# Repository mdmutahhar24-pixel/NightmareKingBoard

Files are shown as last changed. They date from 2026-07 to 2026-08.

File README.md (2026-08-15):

# NightmareKingBoard
A TKL Keyboard based of the Hollow Knight boss Nightmare King Grimm. (Very bad representation)





This keyboard features a red and black case, with RGB lighting, and a rotary encoder. This was coded with QMK firmware.

For more information, please check out the BOM or the Journals.

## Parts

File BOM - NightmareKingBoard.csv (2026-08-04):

Item ID | Item name | Website | Price | Quantity | Role in Keyboard | Notes
206-3 | Raspberry Pi Pico | https://www.pishop.us/product/raspberry-pi-rp2040/?src=raspberrypi | $0.80 | 1 | Microcontroller/Brain
N/A | Gateron Oil King Linear Switch Set | https://www.gateron.com/products/gateron-oil-king-pre-lubed-switches-linear?VariantsId=11428 | $71.50 | 1 | Keyboard Switches | IMPORTANT: These switches come in sets so I chose the 110 switches set.
N/A | BRED Keycap Set - Kraken Keycaps | https://krakenkeyboards.com/products/bred-keycap-set-kraken-keycaps | $39.99 | 1 | Key Caps | IMPORTANT: This also comes in a set
N/A | Rotary Potentiometer Control Black Aluminum Alloy Volume Audio Knob with Triangle Indication Electronic Control Knob 25 X 15mm 6.4mm | https://www.amazon.com/dp/B095X1P8NL?lv=shuf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 | $9.99 | 1 | Encoder Knob
N/A | Rotary Encoder - EC11 | https://keeb.io/products/rotary-encoder-ec11?utm_source=chatgpt.com | $1.99 | 1 | Rotary Encoder
N/A | SK-6812 MINI-E RGB LEDs | https://keeb.io/products/sk-6812-mini-e-rgb-leds-12-pack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 | $23.96 | 4 | RGB LEDs | IMPORTANT: This comes as 25-pack
N/A | M3x5mmx4mm Heatset inserts | https://cnckitchenus.store/products/made-for-voron-gewindeeinsatz-threaded-insert-m3x5x4-100-stk-pcs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 | $11.50 | 1 | Heatset Inserts | IMPORTANT: This comes as a 100 pack
N/A | Screw-in Stabilizer Kit | https://rndkbd.com/products/new-durock-v3-screw-in-stabilizer-kit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 | $17.17 | 1 | Stabilizers | IMPORTANT: This comes as a kit
SKU 75945 | M3x16mm Screws | https://fastenerline.com/products/75945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 | $8.45 | 1 | Screws | IMPORTANT: This comes as a set
161661-1N4148-100 | Through-hole 1N4148 Diodes | https://shop.sayal.com/products/1n4148-100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 | $4.24 | 1 | Diodes | IMPORTANT: This comes in a set of 100
TOTAL: |  |  | $183.80

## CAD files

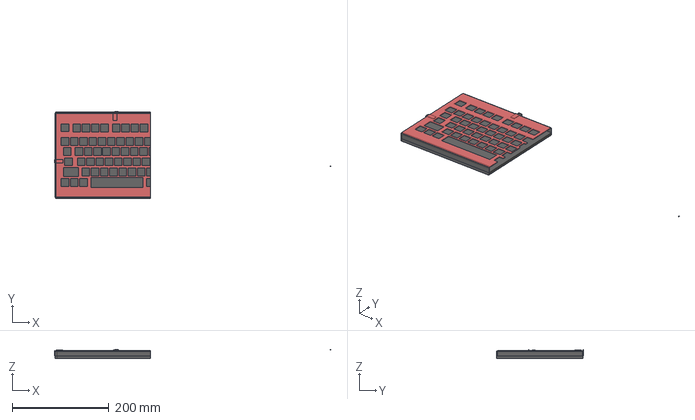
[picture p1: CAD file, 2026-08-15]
CAD/Case Split Right.step
569.1 x 180.2 x 18.0 mm

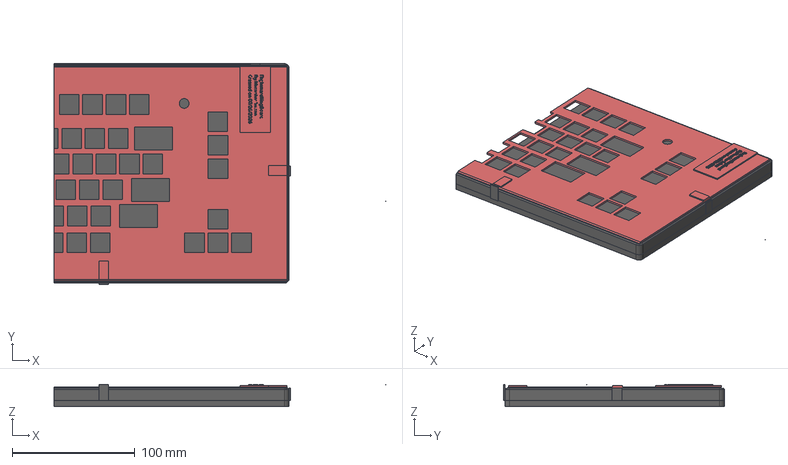
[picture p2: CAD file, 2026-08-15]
CAD/Case Split Left.step
270.8 x 180.1 x 18.0 mm

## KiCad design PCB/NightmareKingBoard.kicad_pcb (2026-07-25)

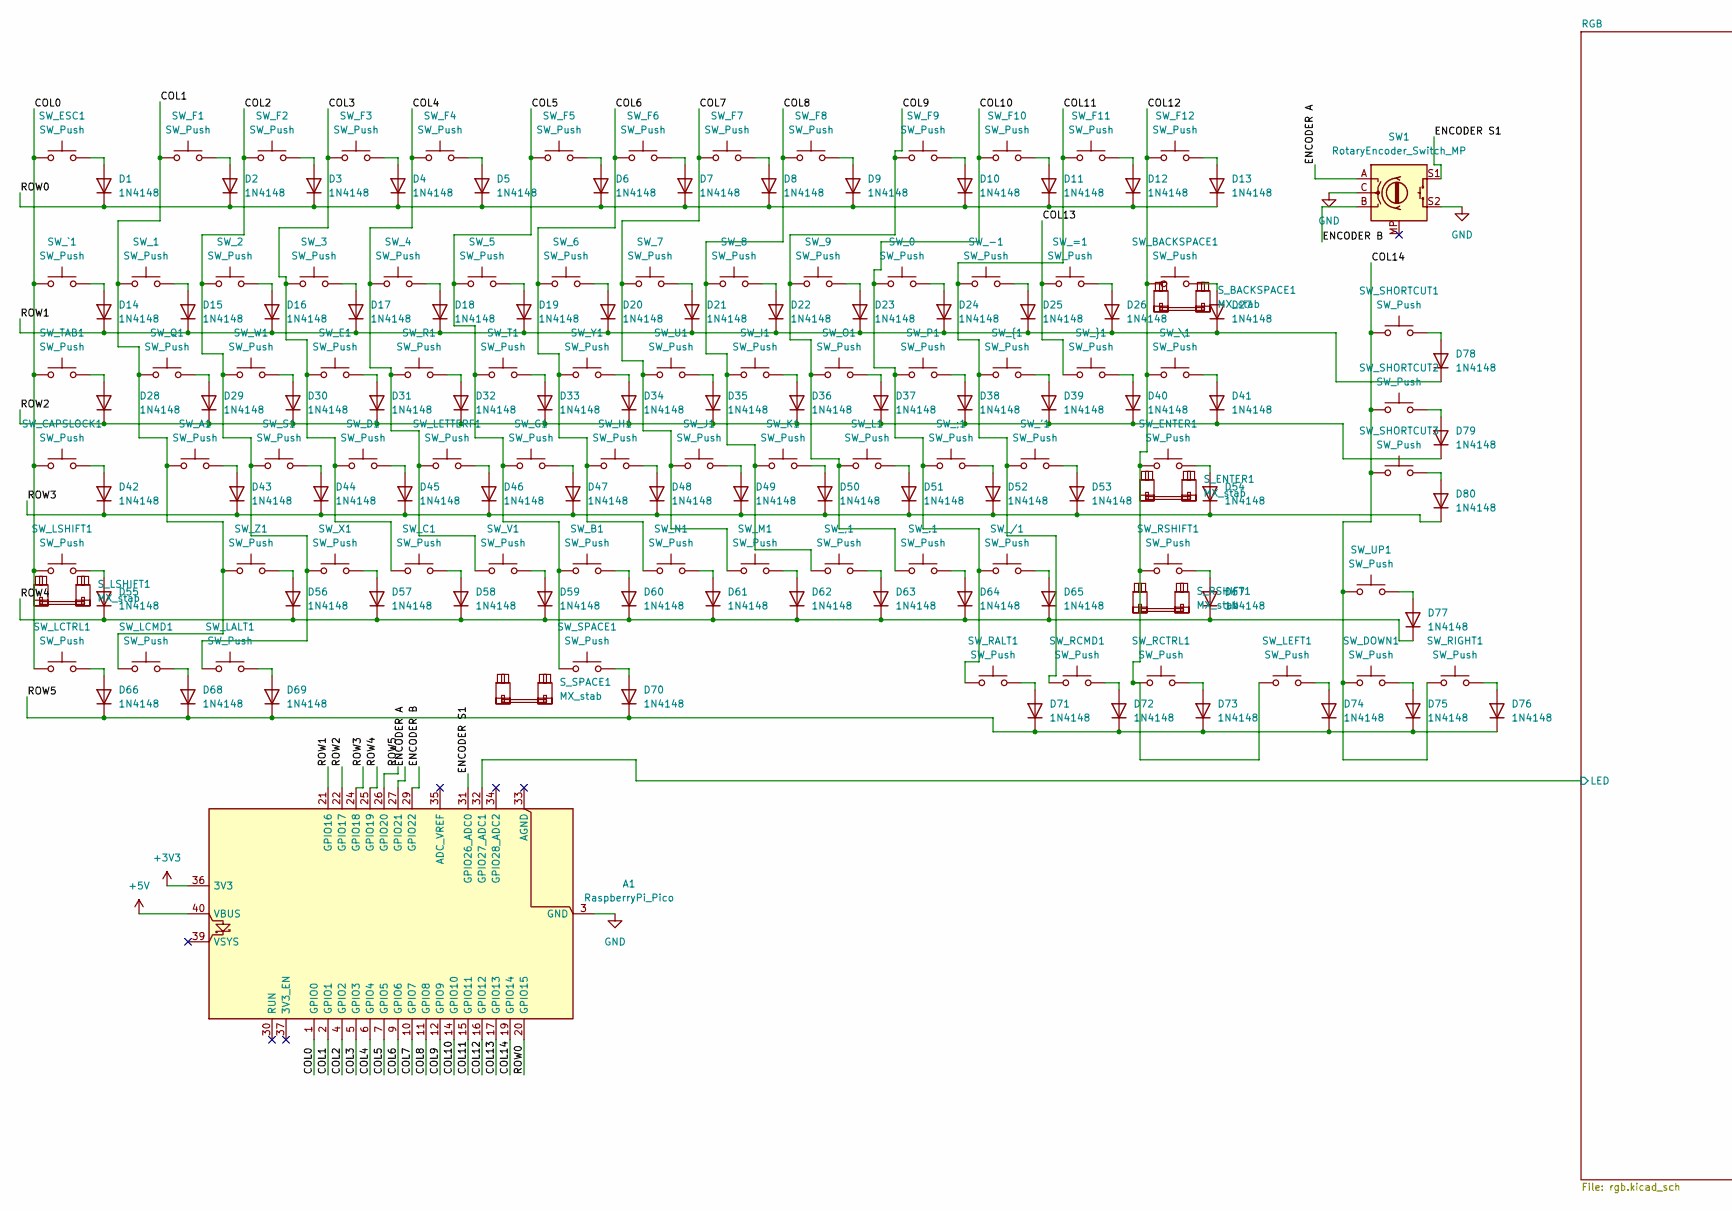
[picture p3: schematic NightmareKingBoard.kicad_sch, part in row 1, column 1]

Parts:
A1: RaspberryPi_Pico; RaspberryPi_Pico_Common_THT
D1, D2, D3, D4, D5, D6, D7, D8, D9, D10, D11, D12, D13, D14, D15, D16, D17, D18, D19, D20, D21, D22, D23, D24, D25, D26, D27, D28, D29, D30, D31, D32, D33, D34, D35, D36, D37, D38, D39, D40, D41, D42, D43, D44, D45, D46, D47, D48, D49, D50, D51, D52, D53, D54, D55, D56, D57, D58, D59, D60, D61, D62, D63, D64, D65, D66, D67, D68, D69, D70, D71, D72, D73, D74, D75, D76, D77, D78, D79, D80: 1N4148; D_DO-35_SOD27_P7.62mm_Horizontal
SW1: RotaryEncoder_Switch_MP; RotaryEncoder_Alps_EC11E-Switch_Vertical_H20mm
SW_0, SW_1, SW_2, SW_3, SW_4, SW_5, SW_6, SW_7, SW_8, SW_9, SW_.1: SW_Push; SW_MX_1u
SW_'1: SW_Push; SW_MX_1u
SW_,1: SW_Push; SW_MX_1u
SW_-1: SW_Push; SW_MX_1u
SW_/1: SW_Push; SW_MX_1u
SW_;1: SW_Push; SW_MX_1u
SW_=1: SW_Push; SW_MX_1u
SW_A1: SW_Push; SW_MX_1u
SW_B1: SW_Push; SW_MX_1u
SW_BACKSPACE1: SW_Push; SW_MX_1u
SW_C1: SW_Push; SW_MX_1u
SW_CAPSLOCK1: SW_Push; SW_MX_1.75u
SW_D1: SW_Push; SW_MX_1u
SW_DOWN1: SW_Push; SW_MX_1u
SW_E1: SW_Push; SW_MX_1u
SW_ENTER1: SW_Push; SW_MX_1u
SW_ESC1: SW_Push; SW_MX_1u
SW_F1, SW_F2, SW_F3, SW_F4, SW_F5, SW_F6, SW_F7, SW_F8, SW_F9, SW_F10, SW_F11, SW_F12: SW_Push; SW_MX_1u
SW_G1: SW_Push; SW_MX_1u
SW_H1: SW_Push; SW_MX_1u
SW_I1: SW_Push; SW_MX_1u
SW_J1: SW_Push; SW_MX_1u
SW_K1: SW_Push; SW_MX_1u
SW_L1: SW_Push; SW_MX_1u
SW_LALT1: SW_Push; SW_MX_1u
SW_LCMD1: SW_Push; SW_MX_1u
SW_LCTRL1: SW_Push; SW_MX_1u
SW_LEFT1: SW_Push; SW_MX_1u
SW_LETTERF1: SW_Push; SW_MX_1u
SW_LSHIFT1: SW_Push; SW_MX_1u
SW_M1: SW_Push; SW_MX_1u
SW_N1: SW_Push; SW_MX_1u
SW_O1: SW_Push; SW_MX_1u
SW_P1: SW_Push; SW_MX_1u
SW_Q1: SW_Push; SW_MX_1u
SW_R1: SW_Push; SW_MX_1u
SW_RALT1: SW_Push; SW_MX_1u
SW_RCMD1: SW_Push; SW_MX_1u
SW_RCTRL1: SW_Push; SW_MX_1u
SW_RIGHT1: SW_Push; SW_MX_1u
SW_RSHIFT1: SW_Push; SW_MX_1u
SW_S1: SW_Push; SW_MX_1u
SW_SHORTCUT1, SW_SHORTCUT2, SW_SHORTCUT3: SW_Push; SW_MX_1u
SW_SPACE1: SW_Push; SW_MX_1u
SW_T1: SW_Push; SW_MX_1u
SW_TAB1: SW_Push; SW_MX_1.5u
SW_U1: SW_Push; SW_MX_1u
SW_UP1: SW_Push; SW_MX_1u
SW_V1: SW_Push; SW_MX_1u
SW_W1: SW_Push; SW_MX_1u
SW_X1: SW_Push; SW_MX_1u
SW_Y1: SW_Push; SW_MX_1u
SW_Z1: SW_Push; SW_MX_1u
SW_\1: SW_Push; SW_MX_1u
SW_`1: SW_Push; SW_MX_1u
SW_{1: SW_Push; SW_MX_1u
SW_}1: SW_Push; SW_MX_1u
S_BACKSPACE1: MX_stab; STAB_MX_2u
S_ENTER1: MX_stab; STAB_MX_2.25u
S_LSHIFT1: MX_stab; STAB_MX_2.25u
S_RSHIFT1: MX_stab; STAB_MX_2.25u
S_SPACE1: MX_stab; STAB_MX_P_6.25u

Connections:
+3V3: A1.36 (3V3)
+5V: A1.40 (VBUS); also elsewhere on the board
/COL0: A1.1 (GPIO0), SW_CAPSLOCK1.1, SW_ESC1.1, SW_LCTRL1.1, SW_LSHIFT1.1, SW_TAB1.1, SW_`1.1
/COL1: A1.2 (GPIO1), SW_1.1, SW_A1.1, SW_F1.1, SW_LCMD1.1, SW_Q1.1, SW_Z1.1
/COL2: A1.4 (GPIO2), SW_2.1, SW_F2.1, SW_LALT1.1, SW_S1.1, SW_W1.1, SW_X1.1
/COL3: A1.5 (GPIO3), SW_3.1, SW_C1.1, SW_D1.1, SW_E1.1, SW_F3.1
/COL4: A1.6 (GPIO4), SW_4.1, SW_F4.1, SW_LETTERF1.1, SW_R1.1, SW_V1.1
/COL5: A1.7 (GPIO5), SW_5.1, SW_B1.1, SW_F5.1, SW_G1.1, SW_SPACE1.1, SW_T1.1
/COL6: A1.9 (GPIO6), SW_6.1, SW_F6.1, SW_H1.1, SW_N1.1, SW_Y1.1
/COL7: A1.10 (GPIO7), SW_7.1, SW_F7.1, SW_J1.1, SW_M1.1, SW_U1.1
/COL8: A1.11 (GPIO8), SW_8.1, SW_,1.1, SW_F8.1, SW_I1.1, SW_K1.1
/COL9: A1.12 (GPIO9), SW_9.1, SW_.1.1, SW_F9.1, SW_L1.1, SW_O1.1
/COL10: A1.14 (GPIO10), SW_0.1, SW_/1.1, SW_;1.1, SW_F10.1, SW_P1.1, SW_RALT1.1
/COL11: A1.15 (GPIO11), SW_'1.1, SW_-1.1, SW_F11.1, SW_RCMD1.1, SW_{1.1
/COL12: A1.16 (GPIO12), SW_BACKSPACE1.1, SW_ENTER1.1, SW_F12.1, SW_LEFT1.1, SW_RCTRL1.1, SW_RSHIFT1.1, SW_\1.1
/COL13: A1.17 (GPIO13), SW_=1.1, SW_}1.1
/COL14: A1.19 (GPIO14), SW_DOWN1.1, SW_RIGHT1.1, SW_SHORTCUT1.1, SW_SHORTCUT2.1, SW_SHORTCUT3.1, SW_UP1.1
/ENCODER A: A1.27 (GPIO21), SW1.A
/ENCODER B: A1.29 (GPIO22), SW1.B
/ENCODER S1: A1.31 (GPIO26_ADC0), SW1.S1
/RGB/LED: A1.32 (GPIO27_ADC1); also elsewhere on the board
/ROW0: A1.20 (GPIO15), D1.1 (K), D2.1 (K), D3.1 (K), D4.1 (K), D5.1 (K), D6.1 (K), D7.1 (K), D8.1 (K), D9.1 (K), D10.1 (K), D11.1 (K), D12.1 (K), D13.1 (K)
/ROW1: A1.21 (GPIO16), D14.1 (K), D15.1 (K), D16.1 (K), D17.1 (K), D18.1 (K), D19.1 (K), D20.1 (K), D21.1 (K), D22.1 (K), D23.1 (K), D24.1 (K), D25.1 (K), D26.1 (K), D27.1 (K), D78.1 (K)
/ROW2: A1.22 (GPIO17), D28.1 (K), D29.1 (K), D30.1 (K), D31.1 (K), D32.1 (K), D33.1 (K), D34.1 (K), D35.1 (K), D36.1 (K), D37.1 (K), D38.1 (K), D39.1 (K), D40.1 (K), D41.1 (K), D79.1 (K)
/ROW3: A1.24 (GPIO18), D42.1 (K), D43.1 (K), D44.1 (K), D45.1 (K), D46.1 (K), D47.1 (K), D48.1 (K), D49.1 (K), D50.1 (K), D51.1 (K), D52.1 (K), D53.1 (K), D54.1 (K), D80.1 (K)
/ROW4: A1.25 (GPIO19), D55.1 (K), D56.1 (K), D57.1 (K), D58.1 (K), D59.1 (K), D60.1 (K), D61.1 (K), D62.1 (K), D63.1 (K), D64.1 (K), D65.1 (K), D67.1 (K), D77.1 (K)
/ROW5: A1.26 (GPIO20), D66.1 (K), D68.1 (K), D69.1 (K), D70.1 (K), D71.1 (K), D72.1 (K), D73.1 (K), D74.1 (K), D75.1 (K), D76.1 (K)
GND: A1.3 (GND), A1.8 (GND), A1.13 (GND), A1.18 (GND), A1.23 (GND), A1.28 (GND), A1.38 (GND), SW1.C, SW1.S2; also elsewhere on the board
unnamed: D1.2 (A), SW_ESC1.2
unnamed: D2.2 (A), SW_F1.2
unnamed: D3.2 (A), SW_F2.2
unnamed: D4.2 (A), SW_F3.2
unnamed: D5.2 (A), SW_F4.2
unnamed: D6.2 (A), SW_F5.2
unnamed: D7.2 (A), SW_F6.2
unnamed: D8.2 (A), SW_F7.2
unnamed: D9.2 (A), SW_F8.2
unnamed: D10.2 (A), SW_F9.2
unnamed: D11.2 (A), SW_F10.2
unnamed: D12.2 (A), SW_F11.2
unnamed: D13.2 (A), SW_F12.2
unnamed: D14.2 (A), SW_`1.2
unnamed: D15.2 (A), SW_1.2
unnamed: D16.2 (A), SW_2.2
unnamed: D17.2 (A), SW_3.2
unnamed: D18.2 (A), SW_4.2
unnamed: D19.2 (A), SW_5.2
unnamed: D20.2 (A), SW_6.2
unnamed: D21.2 (A), SW_7.2
unnamed: D22.2 (A), SW_8.2
unnamed: D23.2 (A), SW_9.2
unnamed: D24.2 (A), SW_0.2
unnamed: D25.2 (A), SW_-1.2
unnamed: D26.2 (A), SW_=1.2
unnamed: D27.2 (A), SW_BACKSPACE1.2
unnamed: D28.2 (A), SW_TAB1.2
unnamed: D29.2 (A), SW_Q1.2
unnamed: D30.2 (A), SW_W1.2
unnamed: D31.2 (A), SW_E1.2
unnamed: D32.2 (A), SW_R1.2
unnamed: D33.2 (A), SW_T1.2
unnamed: D34.2 (A), SW_Y1.2
unnamed: D35.2 (A), SW_U1.2
unnamed: D36.2 (A), SW_I1.2
unnamed: D37.2 (A), SW_O1.2
unnamed: D38.2 (A), SW_P1.2
unnamed: D39.2 (A), SW_{1.2
unnamed: D40.2 (A), SW_}1.2
unnamed: D41.2 (A), SW_\1.2
unnamed: D42.2 (A), SW_CAPSLOCK1.2
unnamed: D43.2 (A), SW_A1.2
unnamed: D44.2 (A), SW_S1.2
unnamed: D45.2 (A), SW_D1.2
unnamed: D46.2 (A), SW_LETTERF1.2
unnamed: D47.2 (A), SW_G1.2
unnamed: D48.2 (A), SW_H1.2
unnamed: D49.2 (A), SW_J1.2
unnamed: D50.2 (A), SW_K1.2
unnamed: D51.2 (A), SW_L1.2
unnamed: D52.2 (A), SW_;1.2
unnamed: D53.2 (A), SW_'1.2
unnamed: D54.2 (A), SW_ENTER1.2
unnamed: D55.2 (A), SW_LSHIFT1.2
unnamed: D56.2 (A), SW_Z1.2
unnamed: D57.2 (A), SW_X1.2
unnamed: D58.2 (A), SW_C1.2
unnamed: D59.2 (A), SW_V1.2
unnamed: D60.2 (A), SW_B1.2
unnamed: D61.2 (A), SW_N1.2
unnamed: D62.2 (A), SW_M1.2
unnamed: D63.2 (A), SW_,1.2
unnamed: D64.2 (A), SW_.1.2
unnamed: D65.2 (A), SW_/1.2
unnamed: D66.2 (A), SW_LCTRL1.2
unnamed: D67.2 (A), SW_RSHIFT1.2
unnamed: D68.2 (A), SW_LCMD1.2
unnamed: D69.2 (A), SW_LALT1.2
unnamed: D70.2 (A), SW_SPACE1.2
unnamed: D71.2 (A), SW_RALT1.2
unnamed: D72.2 (A), SW_RCMD1.2
unnamed: D73.2 (A), SW_RCTRL1.2
unnamed: D74.2 (A), SW_LEFT1.2
unnamed: D75.2 (A), SW_DOWN1.2
unnamed: D76.2 (A), SW_RIGHT1.2
unnamed: D77.2 (A), SW_UP1.2
unnamed: D78.2 (A), SW_SHORTCUT1.2
unnamed: D79.2 (A), SW_SHORTCUT2.2
unnamed: D80.2 (A), SW_SHORTCUT3.2

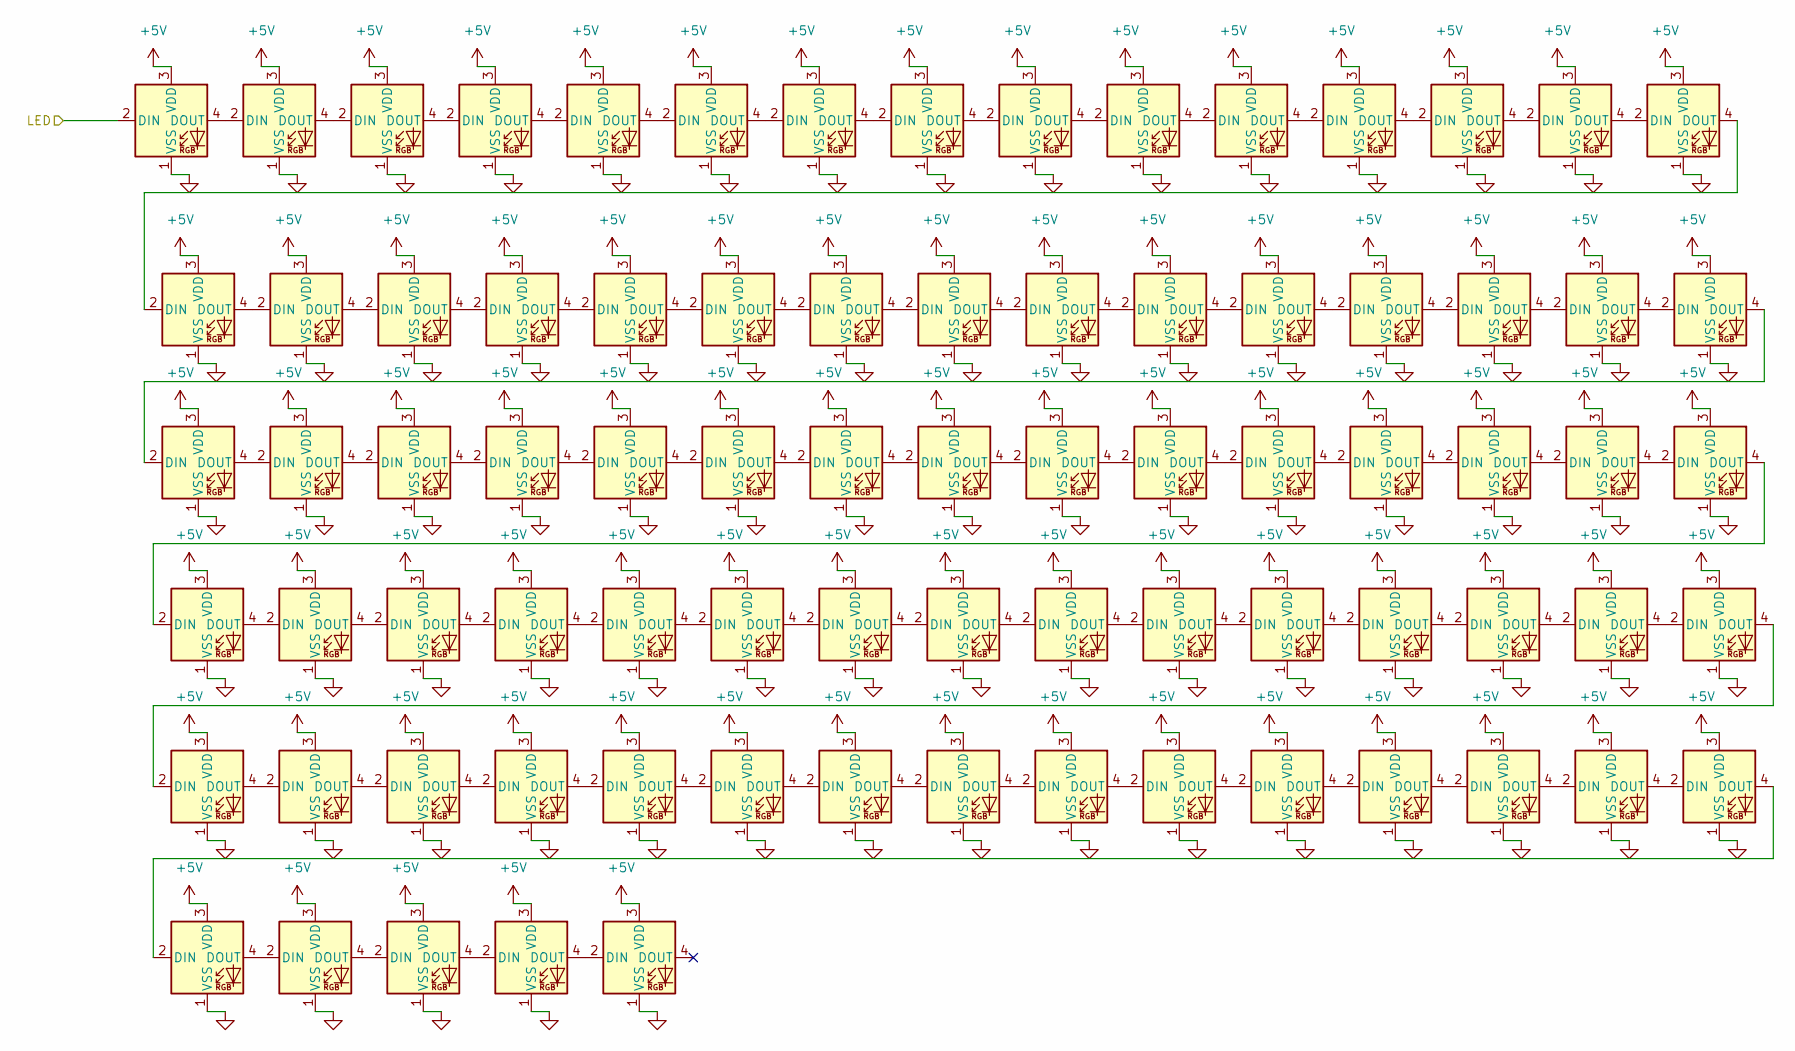
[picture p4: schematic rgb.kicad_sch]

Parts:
D81, D82, D83, D84, D85, D86, D87, D88, D89, D90, D91, D92, D93, D94, D95, D96, D97, D98, D99, D100, D101, D102, D103, D104, D105, D106, D107, D108, D109, D110, D111, D112, D113, D114, D115, D116, D117, D118, D119, D120, D121, D122, D123, D124, D125, D126, D127, D128, D129, D130, D131, D132, D133, D134, D135, D136, D137, D138, D139, D140, D141, D142, D143, D144, D145, D146, D147, D148, D149, D150, D151, D152, D153, D154, D155, D156, D157, D158, D159, D160: SK6812MINI-E; LED_SK6812MINI-E_3.2x2.8mm_P1.5mm_ReverseMount

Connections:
+5V: D81.3 (VDD), D82.3 (VDD), D83.3 (VDD), D84.3 (VDD), D85.3 (VDD), D86.3 (VDD), D87.3 (VDD), D88.3 (VDD), D89.3 (VDD), D90.3 (VDD), D91.3 (VDD), D92.3 (VDD), D93.3 (VDD), D94.3 (VDD), D95.3 (VDD), D96.3 (VDD), D97.3 (VDD), D98.3 (VDD), D99.3 (VDD), D100.3 (VDD), D101.3 (VDD), D102.3 (VDD), D103.3 (VDD), D104.3 (VDD), D105.3 (VDD), D106.3 (VDD), D107.3 (VDD), D108.3 (VDD), D109.3 (VDD), D110.3 (VDD), D111.3 (VDD), D112.3 (VDD), D113.3 (VDD), D114.3 (VDD), D115.3 (VDD), D116.3 (VDD), D117.3 (VDD), D118.3 (VDD), D119.3 (VDD), D120.3 (VDD), D121.3 (VDD), D122.3 (VDD), D123.3 (VDD), D124.3 (VDD), D125.3 (VDD), D126.3 (VDD), D127.3 (VDD), D128.3 (VDD), D129.3 (VDD), D130.3 (VDD), D131.3 (VDD), D132.3 (VDD), D133.3 (VDD), D134.3 (VDD), D135.3 (VDD), D136.3 (VDD), D137.3 (VDD), D138.3 (VDD), D139.3 (VDD), D140.3 (VDD), D141.3 (VDD), D142.3 (VDD), D143.3 (VDD), D144.3 (VDD), D145.3 (VDD), D146.3 (VDD), D147.3 (VDD), D148.3 (VDD), D149.3 (VDD), D150.3 (VDD), D151.3 (VDD), D152.3 (VDD), D153.3 (VDD), D154.3 (VDD), D155.3 (VDD), D156.3 (VDD), D157.3 (VDD), D158.3 (VDD), D159.3 (VDD), D160.3 (VDD); also elsewhere on the board
/RGB/LED: D81.2 (DIN); also elsewhere on the board
GND: D81.1 (VSS), D82.1 (VSS), D83.1 (VSS), D84.1 (VSS), D85.1 (VSS), D86.1 (VSS), D87.1 (VSS), D88.1 (VSS), D89.1 (VSS), D90.1 (VSS), D91.1 (VSS), D92.1 (VSS), D93.1 (VSS), D94.1 (VSS), D95.1 (VSS), D96.1 (VSS), D97.1 (VSS), D98.1 (VSS), D99.1 (VSS), D100.1 (VSS), D101.1 (VSS), D102.1 (VSS), D103.1 (VSS), D104.1 (VSS), D105.1 (VSS), D106.1 (VSS), D107.1 (VSS), D108.1 (VSS), D109.1 (VSS), D110.1 (VSS), D111.1 (VSS), D112.1 (VSS), D113.1 (VSS), D114.1 (VSS), D115.1 (VSS), D116.1 (VSS), D117.1 (VSS), D118.1 (VSS), D119.1 (VSS), D120.1 (VSS), D121.1 (VSS), D122.1 (VSS), D123.1 (VSS), D124.1 (VSS), D125.1 (VSS), D126.1 (VSS), D127.1 (VSS), D128.1 (VSS), D129.1 (VSS), D130.1 (VSS), D131.1 (VSS), D132.1 (VSS), D133.1 (VSS), D134.1 (VSS), D135.1 (VSS), D136.1 (VSS), D137.1 (VSS), D138.1 (VSS), D139.1 (VSS), D140.1 (VSS), D141.1 (VSS), D142.1 (VSS), D143.1 (VSS), D144.1 (VSS), D145.1 (VSS), D146.1 (VSS), D147.1 (VSS), D148.1 (VSS), D149.1 (VSS), D150.1 (VSS), D151.1 (VSS), D152.1 (VSS), D153.1 (VSS), D154.1 (VSS), D155.1 (VSS), D156.1 (VSS), D157.1 (VSS), D158.1 (VSS), D159.1 (VSS), D160.1 (VSS); also elsewhere on the board
unnamed: D81.4 (DOUT), D82.2 (DIN)
unnamed: D82.4 (DOUT), D83.2 (DIN)
unnamed: D83.4 (DOUT), D84.2 (DIN)
unnamed: D84.4 (DOUT), D85.2 (DIN)
unnamed: D85.4 (DOUT), D86.2 (DIN)
unnamed: D86.4 (DOUT), D87.2 (DIN)
unnamed: D87.4 (DOUT), D88.2 (DIN)
unnamed: D88.4 (DOUT), D89.2 (DIN)
unnamed: D89.4 (DOUT), D90.2 (DIN)
unnamed: D90.4 (DOUT), D91.2 (DIN)
unnamed: D91.4 (DOUT), D92.2 (DIN)
unnamed: D92.4 (DOUT), D93.2 (DIN)
unnamed: D93.4 (DOUT), D94.2 (DIN)
unnamed: D94.4 (DOUT), D95.2 (DIN)
unnamed: D95.4 (DOUT), D96.2 (DIN)
unnamed: D96.4 (DOUT), D97.2 (DIN)
unnamed: D97.4 (DOUT), D98.2 (DIN)
unnamed: D98.4 (DOUT), D99.2 (DIN)
unnamed: D99.4 (DOUT), D100.2 (DIN)
unnamed: D100.4 (DOUT), D101.2 (DIN)
unnamed: D101.4 (DOUT), D102.2 (DIN)
unnamed: D102.4 (DOUT), D103.2 (DIN)
unnamed: D103.4 (DOUT), D104.2 (DIN)
unnamed: D104.4 (DOUT), D105.2 (DIN)
unnamed: D105.4 (DOUT), D106.2 (DIN)
unnamed: D106.4 (DOUT), D107.2 (DIN)
unnamed: D107.4 (DOUT), D108.2 (DIN)
unnamed: D108.4 (DOUT), D109.2 (DIN)
unnamed: D109.4 (DOUT), D110.2 (DIN)
unnamed: D110.4 (DOUT), D111.2 (DIN)
unnamed: D111.4 (DOUT), D112.2 (DIN)
unnamed: D112.4 (DOUT), D113.2 (DIN)
unnamed: D113.4 (DOUT), D114.2 (DIN)
unnamed: D114.4 (DOUT), D115.2 (DIN)
unnamed: D115.4 (DOUT), D116.2 (DIN)
unnamed: D116.4 (DOUT), D117.2 (DIN)
unnamed: D117.4 (DOUT), D118.2 (DIN)
unnamed: D118.4 (DOUT), D119.2 (DIN)
unnamed: D119.4 (DOUT), D120.2 (DIN)
unnamed: D120.4 (DOUT), D121.2 (DIN)
unnamed: D121.4 (DOUT), D122.2 (DIN)
unnamed: D122.4 (DOUT), D123.2 (DIN)
unnamed: D123.4 (DOUT), D124.2 (DIN)
unnamed: D124.4 (DOUT), D125.2 (DIN)
unnamed: D125.4 (DOUT), D126.2 (DIN)
unnamed: D126.4 (DOUT), D127.2 (DIN)
unnamed: D127.4 (DOUT), D128.2 (DIN)
unnamed: D128.4 (DOUT), D129.2 (DIN)
unnamed: D129.4 (DOUT), D130.2 (DIN)
unnamed: D130.4 (DOUT), D131.2 (DIN)
unnamed: D131.4 (DOUT), D132.2 (DIN)
unnamed: D132.4 (DOUT), D133.2 (DIN)
unnamed: D133.4 (DOUT), D134.2 (DIN)
unnamed: D134.4 (DOUT), D135.2 (DIN)
unnamed: D135.4 (DOUT), D136.2 (DIN)
unnamed: D136.4 (DOUT), D137.2 (DIN)
unnamed: D137.4 (DOUT), D138.2 (DIN)
unnamed: D138.4 (DOUT), D139.2 (DIN)
unnamed: D139.4 (DOUT), D140.2 (DIN)
unnamed: D140.4 (DOUT), D141.2 (DIN)
unnamed: D141.4 (DOUT), D142.2 (DIN)
unnamed: D142.4 (DOUT), D143.2 (DIN)
unnamed: D143.4 (DOUT), D144.2 (DIN)
unnamed: D144.4 (DOUT), D145.2 (DIN)
unnamed: D145.4 (DOUT), D146.2 (DIN)
unnamed: D146.4 (DOUT), D147.2 (DIN)
unnamed: D147.4 (DOUT), D148.2 (DIN)
unnamed: D148.4 (DOUT), D149.2 (DIN)
unnamed: D149.4 (DOUT), D150.2 (DIN)
unnamed: D150.4 (DOUT), D151.2 (DIN)
unnamed: D151.4 (DOUT), D152.2 (DIN)
unnamed: D152.4 (DOUT), D153.2 (DIN)
unnamed: D153.4 (DOUT), D154.2 (DIN)
unnamed: D154.4 (DOUT), D155.2 (DIN)
unnamed: D155.4 (DOUT), D156.2 (DIN)
unnamed: D156.4 (DOUT), D157.2 (DIN)
unnamed: D157.4 (DOUT), D158.2 (DIN)
unnamed: D158.4 (DOUT), D159.2 (DIN)
unnamed: D159.4 (DOUT), D160.2 (DIN)

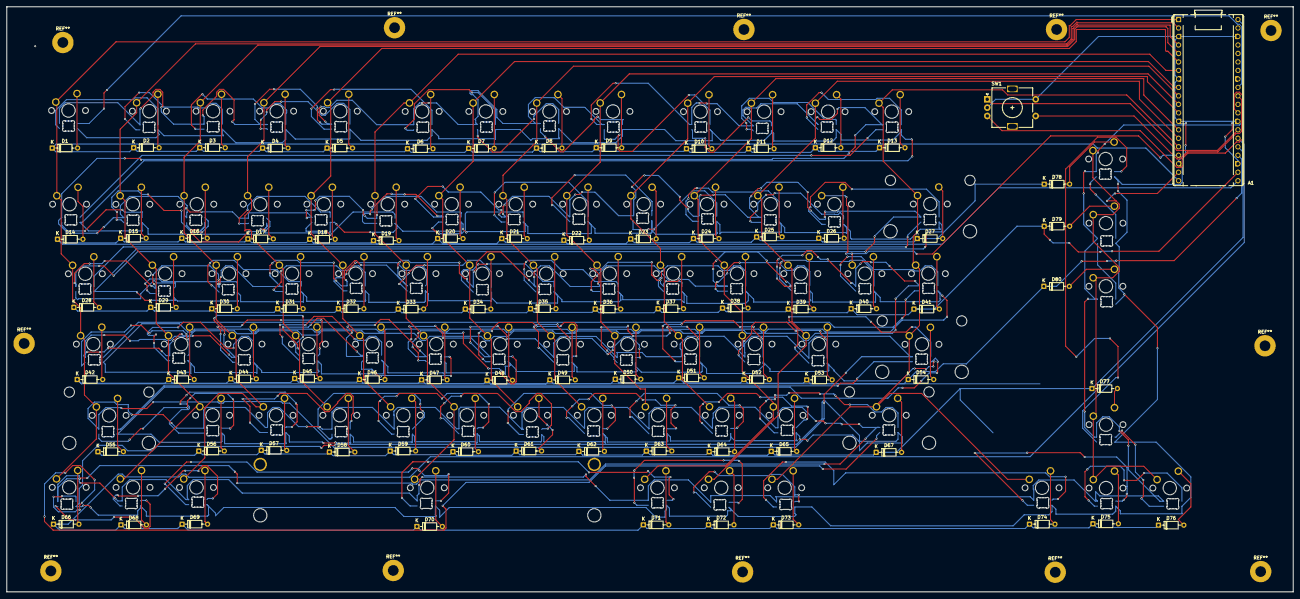
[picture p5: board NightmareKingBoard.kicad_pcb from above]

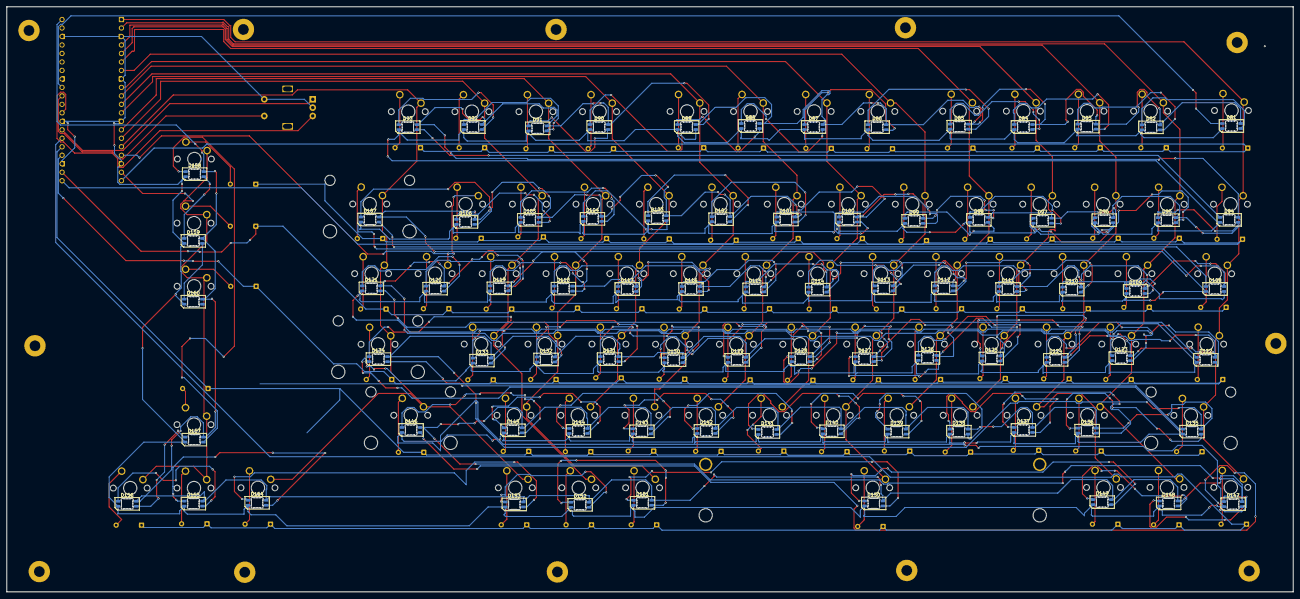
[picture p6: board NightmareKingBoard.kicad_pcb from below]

Board: 2 copper layers, 385.2 x 175.2 mm, 247 parts (80 on the bottom side), 186 nets.

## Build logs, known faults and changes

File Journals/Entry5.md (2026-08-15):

# Journal Entry Five



**Hours logged: 0:40:09.59**

## Stage 5: Firmware
Firmware is now complete! I have coded my matrix, my RGB LEDs and also my rotary encoder! I am going to keep changing this after I build my keyboard, depending on what I feel. For the firmware, I decided to switch over to QMK because of two reasons:
1. I had a lot of experience with it
2. It is easier and had better documentation.

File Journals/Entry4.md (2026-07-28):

# Journal Entry Four

Hours Logged: 04:45:42.21

## Stage 5: Keyboard CAD in OnShape

<strong>Image showing CAD of keyboard<strong>

I have worked on my Keyboard casing in CAD. It was very monotonous since most of the time I just kept fastening 87 keys, and so on. Above is my final keyboard CAD, though it may have small tweaks from time to time. I think this keyboard is a bad representation of what I wanted, but this was the best I could design it.

## Stage 6: Firmware

I just started setting up firmware and still trying to figure things out, so I don't really have anything to say here :P

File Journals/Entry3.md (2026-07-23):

# Journal Entry #3

Hours Logged: 04:52:12.39

## Stage 4: PCB (Continuation from last journal)

<strong>Image of Final PCB</strong>
The PCB is finally over! It took a long time but I managed to do it. I unfortunately cannot change the 3D models of the rotary encoder and switches because I don't know how to do it. I will most likely just add it via OnShape.

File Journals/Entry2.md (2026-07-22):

# Journal Entry Two

Hours Logged: 02:09:46.94

## Stage 3: Schematic (Continued from Last Journal)
Schematic has finally been completed! I finished my RGB LED Chain and connected it to my Raspberry Pi Pico in my Schematic. I can now finally move on to PCB. This was one of the hardest Schematics I have ever done.

## Stage 4 PCB (Incomplete)
<figure>
  
  <figcaption><strong>Image of Schematic Progress</strong></figcaption>
  <br/>
</figure> 

This is an Image of what I have done with my PCB so far. Right now, I have organized all the keys. These will most likely be moved again due to LED lighting and diode positions. The Pico may be moved depending on how much room I have. I will then move on to routing the PCB.

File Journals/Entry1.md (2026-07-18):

# Journal Entry 1

**Hours Logged:** 05:05:38.93

## Stage 1: Research
Before doing anything related to the keyboard, I wanted to research what types of items were the best for a gaming keyboard (since I wanted it for gaming). This is what I gathered:
- TKL keyboards are most preffered for gaming
- Gasteron Oil King Switches were good for gaming
- Most gaming keyboards had RGB lights

## Stage 2: Plan my Keyboard
I planned to make a keyboard based off <a href="https://hollowknight.fandom.com/wiki/Nightmare_King_Grimm">Nightmare King Grimm (NKG for short)</a> which is one of the coolest bosses in the game of Hollow Knight.
I did some additional Research to make my Keyboard theme match with NKG. This is what I gathered and updated my BOM with:
- Red and Black fit with NKG's style so I chose the Red and black BRED keycap set from Kraken Keycaps
- SK-6812 MINI-E RGB LEDs were chosed for the LEDs since it was preffered for keyboards
- Aluminum Sand Blasted Knurling Encoder Knobs (Red) to style my encoder
- Rotary Encoder for a custom touch
- Raspberry Pi Pico

## Stage 3: Schematic
<figure>

<figcaption><strong>Image of Schematic Progress</strong></figcaption>
  <br/>
</figure>  

Since I had finished my BOM, I started with my PCB schematic. I had used about (I am not sure) 87 switches. I organized them into how a keyboard looks. Right now this is in progress since I am still working on wiring the matrix, working on the LEDs, and wiring the Rotary Encoder.

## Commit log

2026-07-17 Rename BOM - NightmareKingBoard.csv to BOM.csv
    [BOM.csv]
2026-07-18 Add schematic image and update PCB description
    Added an image of the schematic progress and updated the description of the PCB schematic work.
2026-07-18 Replace Orpheus Pico with Raspberry Pi Pico in BOM
    Updated the BOM to replace Orpheus Pico with Raspberry Pi Pico and adjusted item details accordingly.
    [BOM - NightmareKingBoard.csv]
2026-07-18 Update BOM - NightmareKingBoard.csv
    [BOM - NightmareKingBoard.csv]
2026-07-18 Update BOM for Nightmare King Board
    [BOM - NightmareKingBoard.csv]
2026-07-22 Create Journal Entry Two with project updates
    Added details about schematic completion and PCB progress.
2026-07-27 Revise BOM - NightmareKingBoard with new components
    Updated BOM with new items and corrected entries.
    [BOM - NightmareKingBoard.csv]
2026-08-04 Revise BOM - NightmareKingBoard with new items
    Updated item details and prices in the BOM.
    [BOM - NightmareKingBoard.csv]
